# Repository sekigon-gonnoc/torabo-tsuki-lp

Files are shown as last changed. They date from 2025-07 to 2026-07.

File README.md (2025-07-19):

# torabo-tsuki LP

torabo-tsuki LP（トラボ付きLP）はトラックボール付きの無線分割キーボードキットです。

トラックボール(25 or 19mm)の高さを低く抑えることで、キーを打つときや持ち運びの邪魔になりにくくなっています。
無線接続に適したハードウェア・ソフトウェア構成により低消費電力を実現しており、連続して数か月間使用可能です。バッテリーは乾電池なので、残量や安全性を気にしながら定期的に充電する必要がありません。

[BOOTH](https://nogikes.booth.pm/items/7200248)にて販売中です。

**MX版の情報は[こちら](https://github.com/sekigon-gonnoc/torabo-tsuki)**

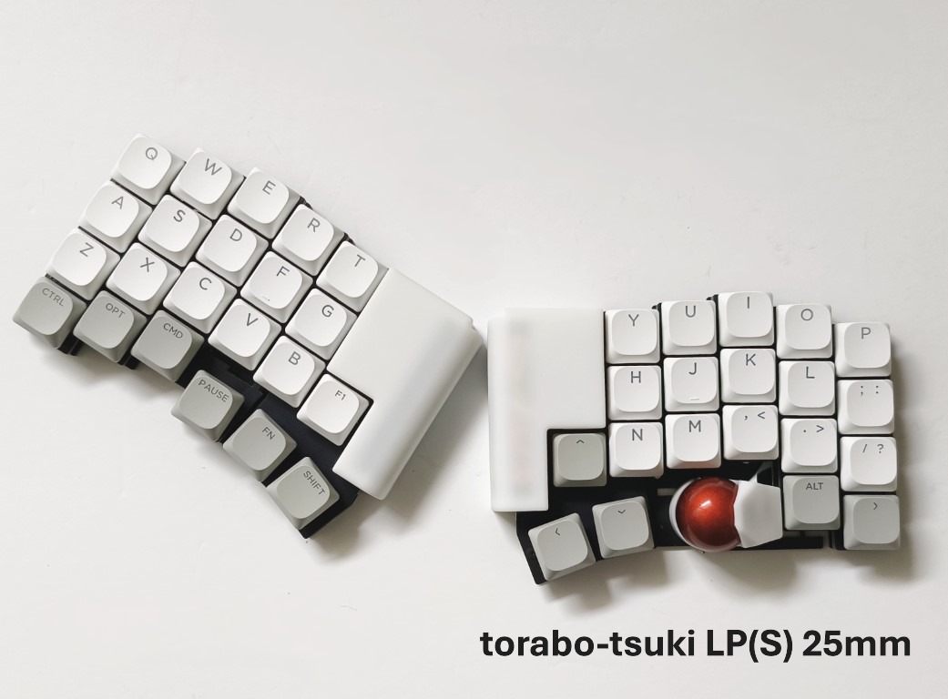
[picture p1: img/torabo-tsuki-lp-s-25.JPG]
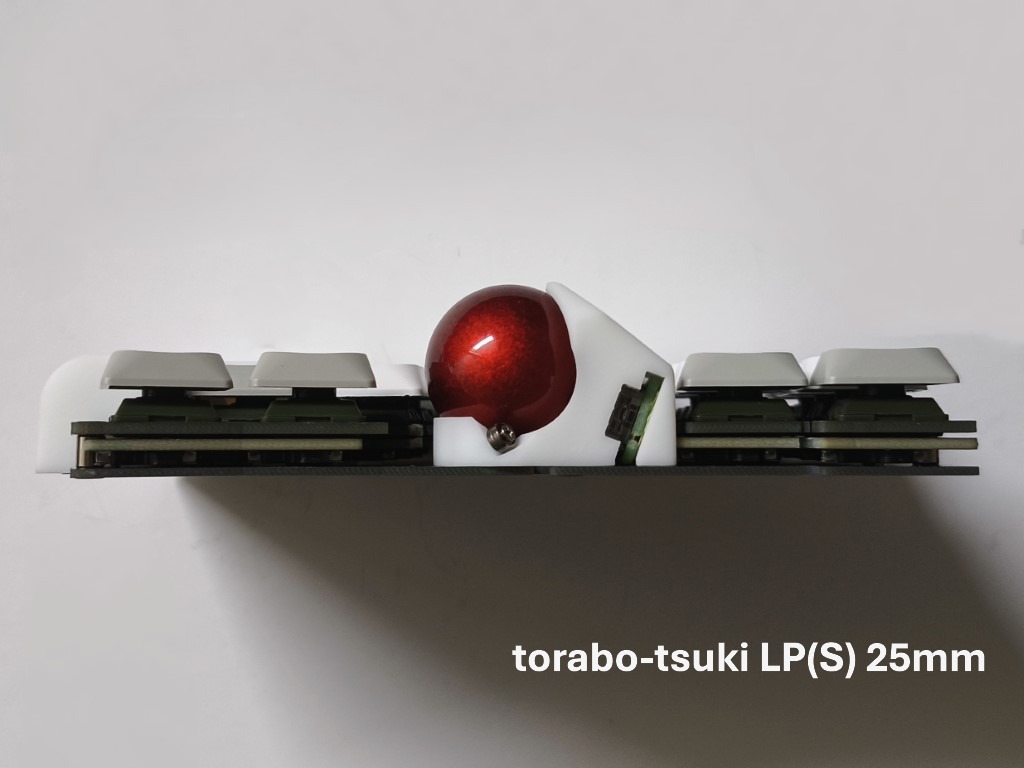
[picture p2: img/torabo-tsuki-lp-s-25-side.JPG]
|||
|-|-|
|Sサイズ, 右25mmボール|Sサイズ, 右25mmボール|
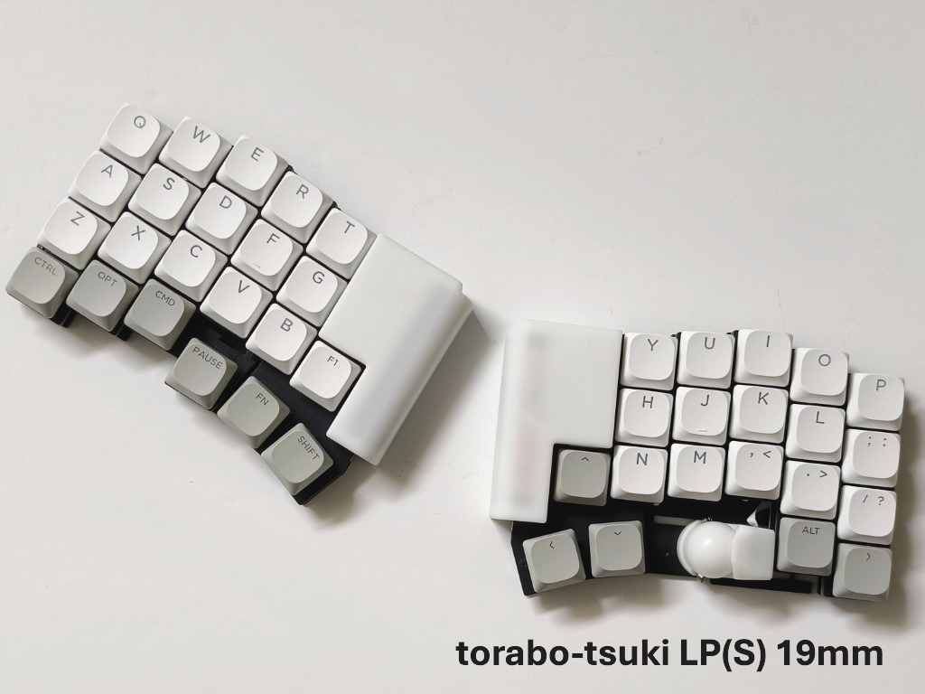
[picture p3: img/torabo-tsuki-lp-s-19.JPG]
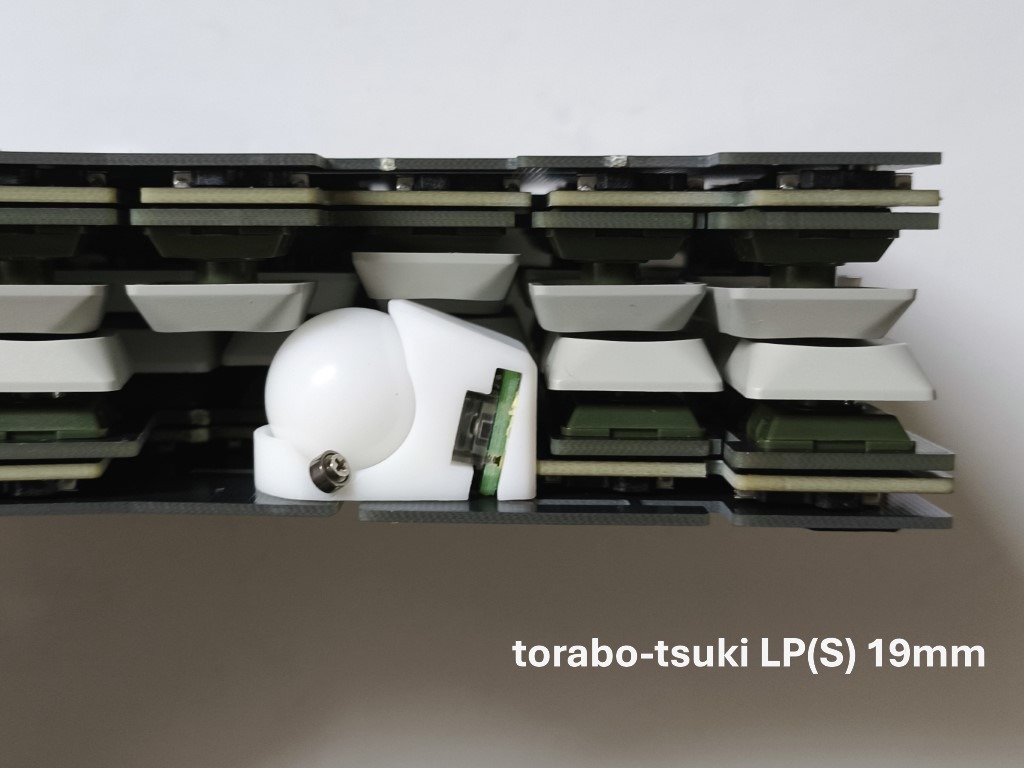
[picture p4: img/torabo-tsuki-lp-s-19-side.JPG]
|||
|Sサイズ, 右19mmボール|Sサイズ, 右19mmボール|

## [ビルドガイド](build-guide.md)

## 特徴

* 主要部品実装済み
  * ソケットやダイオードなどの部品は実装済みです。半田付けが必要な部品は電池ボックスだけです。
* 乾電池各1本で長期間動作
  * Ni-MH電池またはアルカリ電池で動作します。
  * 無線での使用にあわせて調整されたハードウェア・ソフトウェア構成により、乾電池でも数か月間利用できます。
* トラックボールの設置位置が調整可能
  * トラックボールを取り付ける位置を調整して、自分にとって一番操作しやすい位置に設置できます。ボールの高さを抑えたことでキーを打つときの邪魔になりにくなっています。
  * 左トラックボール、デュアルトラックボールにすることもできます。
  * トラックボールのサイズは25mmまたは19mmから選択できます。
* ZMK対応
  * keymap-editorやZMK Studioを使用して簡単にキーマップが変更できます。

## 使用上の注意

* 異臭や煙が出たときは、ただちに使用を中止して電源を切り電池を抜いてください。
* 電池から漏れた液が目に入った場合は、失明する恐れがあるのですぐにきれいな水でよく洗い、医師の診断を受けてください。
* 電池の+-を正しくセットしてください。
* 使い切った電池は速やかに取り出してください。
* 長期間使用しない場合は電池を取り出してください。

## 設計データについて

本リポジトリで基板・トラックボールケース・電池カバーの設計データを公開しています。

ライセンスにしたがって自由に利用していただいて構いませんが、問い合わせには対応しません。

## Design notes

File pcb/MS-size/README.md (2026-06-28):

\# torabo-tsuki LP(MS)

Mサイズの17mmピッチ版です。

動作未確認

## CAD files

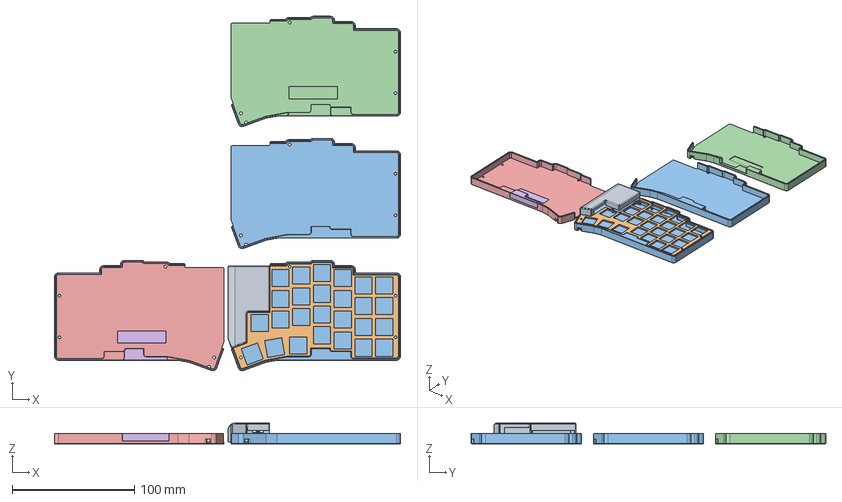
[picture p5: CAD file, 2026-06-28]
3d-models/FreeCAD/option/torabo-tsuki-lp-ms-simple-case.FCStd
283.4 x 290.4 x 17.2 mm
torabo-tsuki-lp-MS-top-key_PCB
case-key x 2
case-trackball
case-trackball001 (Mirror #2)
case-key001 (Mirror #3)

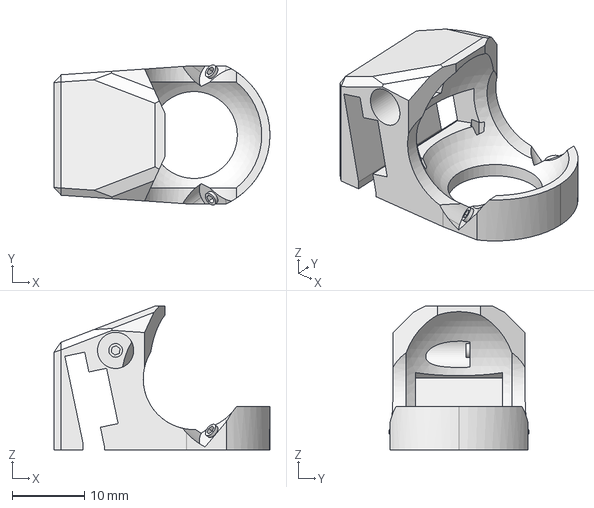
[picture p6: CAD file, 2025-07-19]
3d-models/FreeCAD/trackball-case-19mm.FCStd
29.8 x 19.4 x 19.8 mm

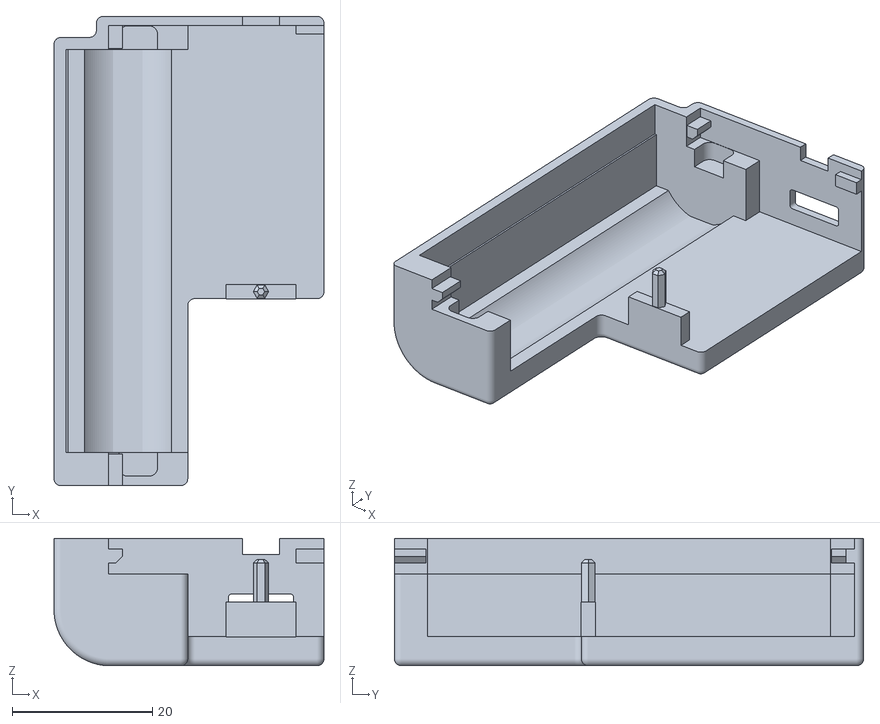
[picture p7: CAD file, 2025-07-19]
3d-models/STL/controller-cover-aa-Body-mirror.stl
38.5 x 67.0 x 18.2

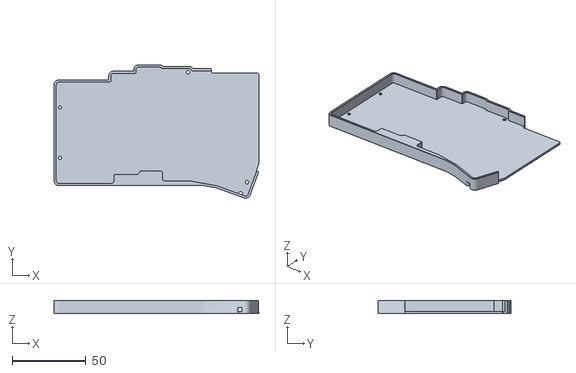
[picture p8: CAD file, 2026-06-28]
3d-models/STL/option/MS-size/torabo-tsuki-lp-MS-simple-case-left-key.stl
138.8 x 90.4 x 8.80

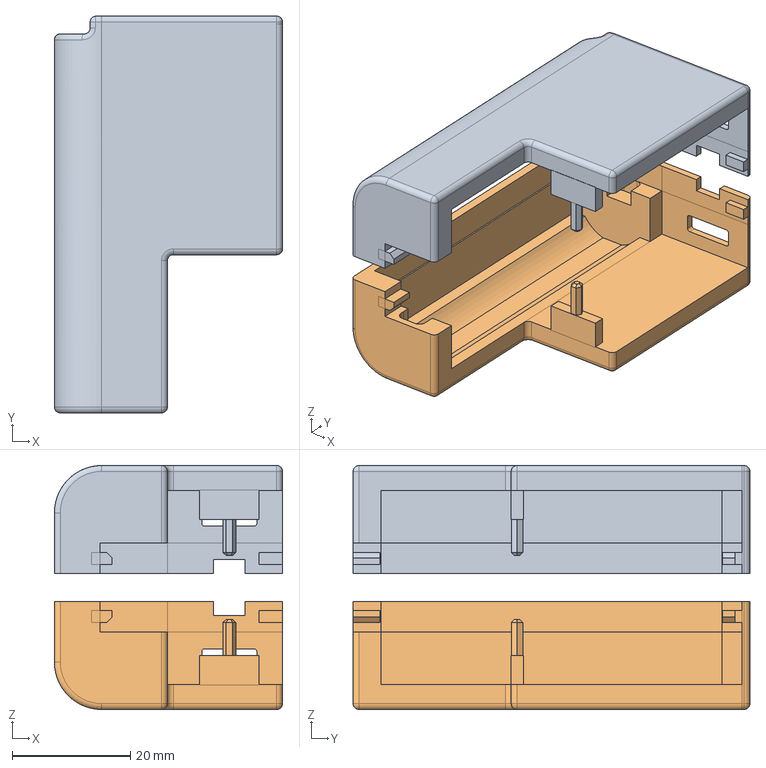
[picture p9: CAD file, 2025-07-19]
3d-models/FreeCAD/controller-cover-aa.FCStd
38.5 x 67.0 x 41.2 mm
Body (Mirror #1)

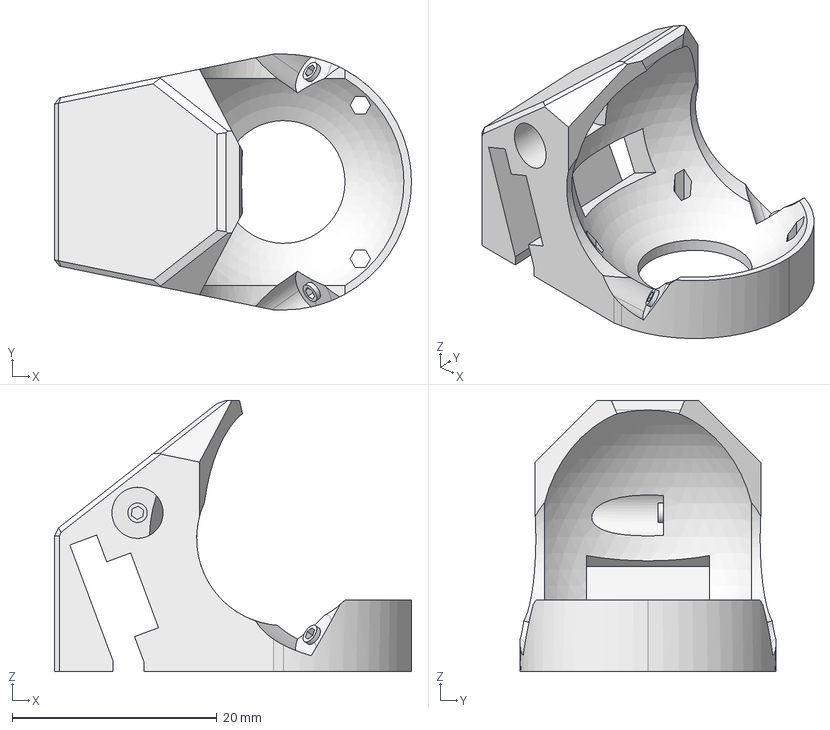
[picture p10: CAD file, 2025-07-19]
3d-models/FreeCAD/trackball-case-25mm.FCStd
34.9 x 25.0 x 26.5 mm

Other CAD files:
3d-models/STL/option/MS-size/torabo-tsuki-lp-MS-simple-case-right-key.stl
3d-models/STL/trackball-case-19mm-Body.stl
3d-models/STL/controller-cover-aa-Body.stl
3d-models/STL/option/MS-size/torabo-tsuki-lp-MS-simple-case-left-tb.stl
3d-models/STL/option/MS-size/torabo-tsuki-lp-MS-simple-case-right-tb.stl
3d-models/STL/trackball-case-25mm-Body.stl

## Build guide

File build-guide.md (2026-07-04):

# ビルドガイド

torabo-tsuki LPシリーズのビルドガイドです。V1とV2では電池ボックスの取り付け周りの手順が異なります。
自分が組み立てるのはどちらかを確認してから手順を進めてください。

## 同梱品

| 名称 | 数  |
| --- | --- |
| メイン基板 | 1 |
| トッププレート | 2 |
| ボトムプレート | 2 |
| 電池ボックス(単三 or 単四) | 2 |
| スペーサー(4.5mm) | 8 |
| ねじ(M2x3.5) | 18  |
| **トラックボール部品** | |
| トラックボールセンサー(14mmマウスセンサーモジュール) | 1 |
| フレキシブルケーブル(0.5mmピッチ、6P、100mm、電極同一面) | 1 |
| ベアリング(4x1.5x2 mm) | 3 |
| ねじ(M1.4) | 3 |
| **BMP Boost同梱の場合** | |
| BMP Boost | 2 |

## 別途必要な部品

| 名称 | 数 | 補足 |
| --- | ----- | --- |
| キースイッチ(Choc V2) | 42(S, XS), 50(M), 64(L) | |
| キーキャップ | 適量  | |
| 25mmトラックボール交換球  or 19.05mm POMボール | 1 | |
| コンスルー | 4 | 13ピン（高さ2.5mm）を使用してください。欠品している場合は12ピンを5個買って、1個を切り離して使ってください |
| 電池カバー、トラックボールケース(25mm or 19mm) | 1式 | 3Dプリントサービスや自前で出力してください。JLC3DPだと送料込みで$5くらいで製造できます（詳細は後述） |
| ゴム足 | 8 | GRIPLUSなど薄型の物がおすすめです |
| 乾電池 | 2 | S,M,Lは単三、XSは単四、Ni-MH可。USBで充電できるリチウム電池内蔵のものを使う場合、必ずキーボードから取り外してから充電してください |
| **オプション** |||
|ケース| 1式 | [シンプルケース](3d-models/STL/option)や有志が公開・販売しているデータを装着できます |
| **BMP Boost別売りの場合** | | |
| BMP Boost | 2 | BLE Micro Pro (無印)は使用できません。入手先:[BOOTH](https://booth.pm/ja/items/1177319), [遊舎工房](https://shop.yushakobo.jp/products/10737) |

## 必要な工具
- はんだごて、はんだ
- ニッパー
- ペンチ
- ドライバー
- （やすり）
- PC
- USBケーブル

## 3Dプリント部品の製造(JLC3DP利用)

[JLC3DP](https://jlc3dp.com/jp/3d-printing-quote)にアクセスします。

[3d-models/STL](3d-models/STL/)フォルダのSTLファイルの中身をJLC3DPにアップロードします。トラックボールケースはサイズが2種類あります。製造時に片方に決めてもいいですし、両方頼んで届いてから考えてもいいです。

電池カバーは、S,M,Lの場合はaaを、XSの場合はaaaを使用してください。V2ではV1から形状が若干変わっています。過去にV1を組み立て済みで、今回V2を組み立てる方は、改めてデータをダウンロードしてください。

また、[シンプルケース](3d-models/STL/option)、[テンティングケース](https://github.com/sekigon-gonnoc/torabo-tsuki-lp-tenting-case)や、有志が公開・販売しているデータを一緒に製造することもできます。ご自分でデザインしたい場合は[シンプルケースのCADデータ](3d-models/FreeCAD/option/torabo-tsuki-lp-simple-case.FCStd)をご活用ください。

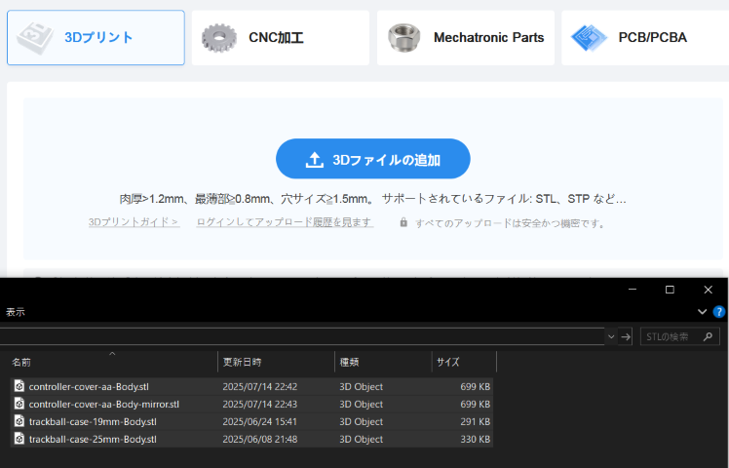
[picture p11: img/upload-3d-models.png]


電池カバー、トラックボールケースについての商品概要は`Enclosure..`から`Plastic Enclosure`を選択します。
ケースについては`Office Appliance...`から`Plastic Keyboard Enclosure`を選択してください。

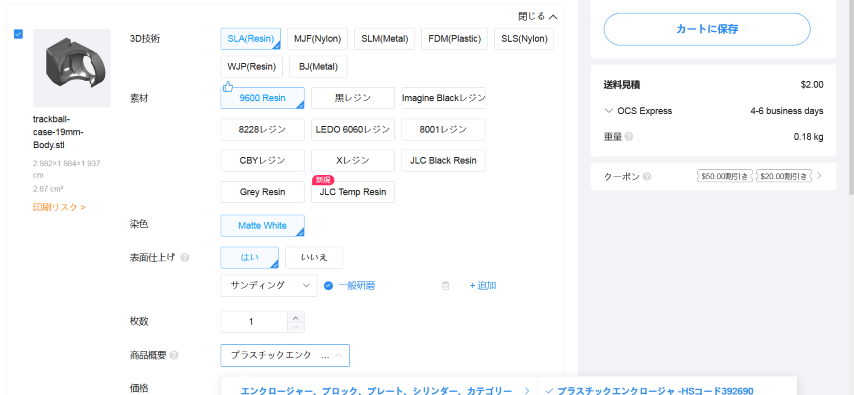
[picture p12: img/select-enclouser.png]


モデルのサムネイルの下に`印刷リスク`の表示がある場合は`はい`をチェックしてください。

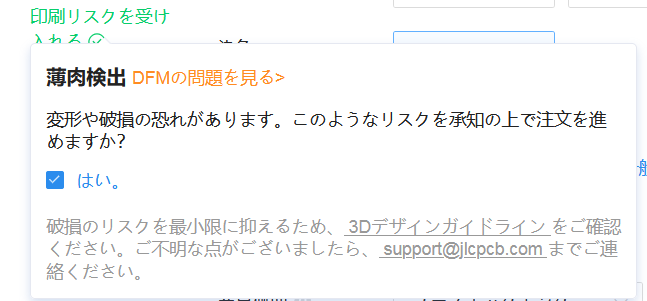
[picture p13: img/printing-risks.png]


カートに保存し、注文手続きを進めます。配送方法はOCSを選択すると2ドルで配送してもらえます（2025年7月時点、月3回まで）。

発注履歴が表示されるようになった状態で数分経ってからタブをリロードすると、ファイル名の横に!マークが表示されることがあります。

その場合は!マークをクリックし、`はい`を選択してください。

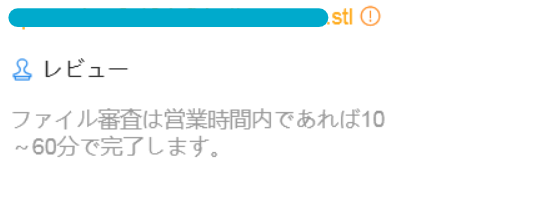
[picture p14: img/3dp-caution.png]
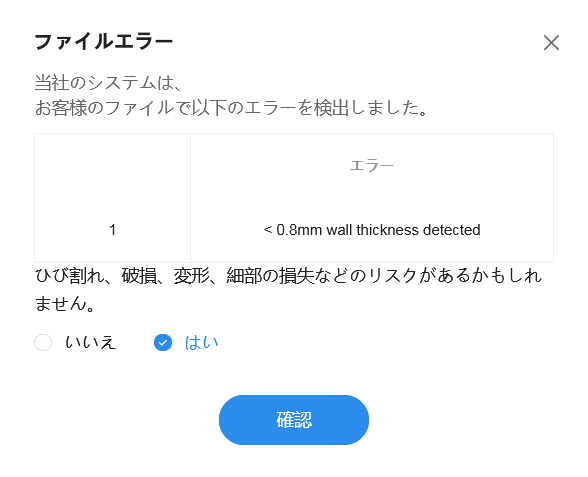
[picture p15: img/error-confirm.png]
|  |  |
| --- | --- |

JLC3DPによるレビュー中にメールで問い合わせが来る場合がありますが、そのまま製造するように依頼してください。
気になる人は自分でCADデータを修正してください。

## 組立手順

### メイン基板のレール部分を折って切り離す

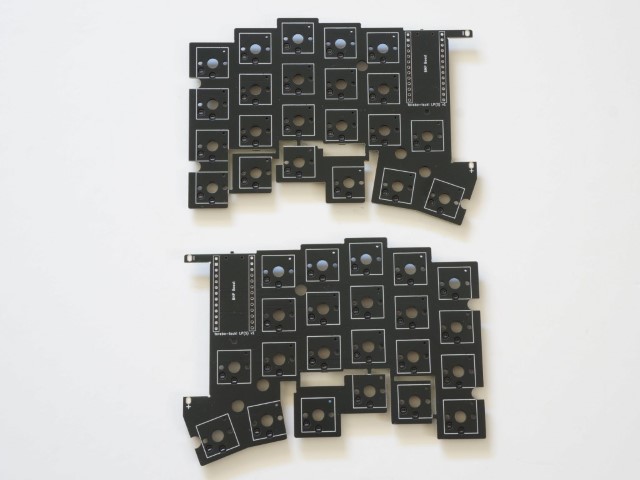
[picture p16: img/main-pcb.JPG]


### メイン基板・トッププレートのトラックボール搭載部分と、トラックボールを搭載しないほうのボトム基板の余剰部分を切り離す

シンプルケースを装着する場合は、ボトムプレートは両側とも余剰部分を切り離します。

ニッパーでそのまま切り離せない場合は、表裏に切れ目を入れてから折り取ることもできますが、ほかの配線を傷つけないように注意してください。

> [!caution]
> 向きを間違えないように注意してください。下記画像は右側にトラックボールを搭載する例です。

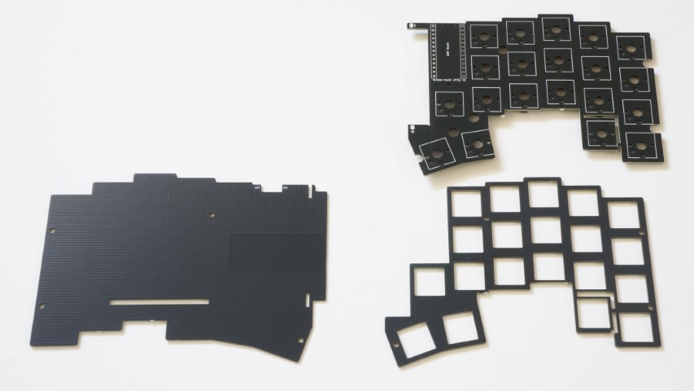
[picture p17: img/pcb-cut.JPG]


### (V1の場合)電池ボックスをはんだ付けする

* 電池ボックスの足を折り曲げます。
  * XSに単四電池ケースを取り付ける場合は基板上のマークよりすこし上に寄せてください。基板の穴はBMP Boost側を使います。マイナス極が上側です。
* ボトムプレートに電池ボックスを載せ、その上からメイン基板を載せます。向きに注意してください。
* 余った足を短く切ってからはんだ付けします。メイン基板とボトム基板がぴったりくっついた状態ではんだ付けするようにしてください。

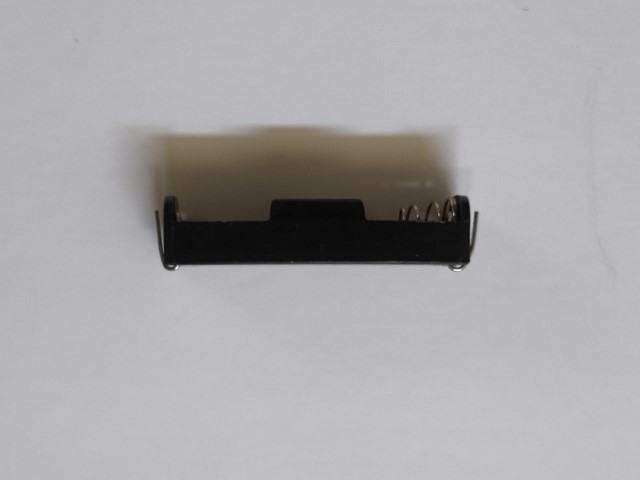
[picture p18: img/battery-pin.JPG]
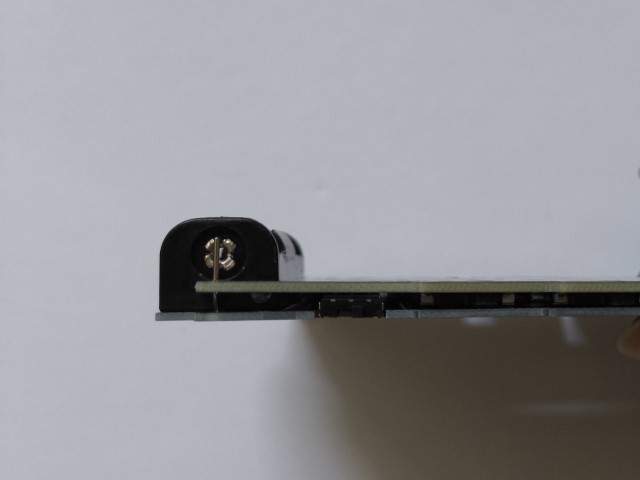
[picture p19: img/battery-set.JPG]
|||
|-|-|
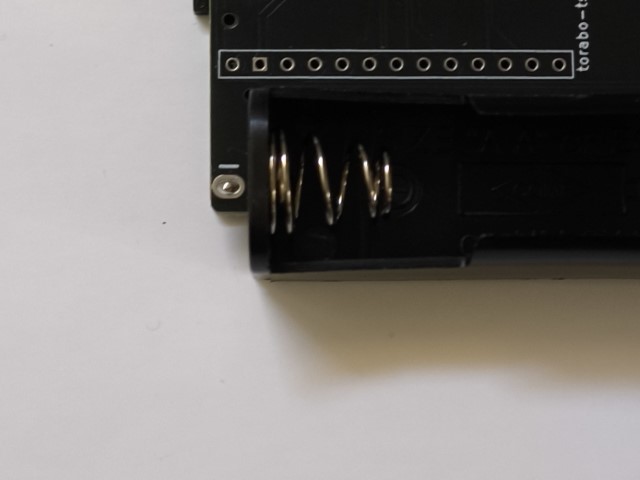
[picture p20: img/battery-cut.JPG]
|||

||
|-|
|単四電池ケースの取り付け位置|

### (V2の場合)電池ボックスを基板に差し込む

torabo-tsuki LP V2では電池ボックスもソケットに差し込むだけで取り付けられます。
ソケットの位置に合わせて電池ボックスの足を折り曲げてから差し込みます。
S,M,Lではパーツ配置の都合で斜め方向に足を曲げ、XSでは真上に曲げてください。

|||
|-|-|
|S,M,L|XS|

* 電池ボックスのピンを折り曲げます。横から見たときピンが真上に向くように折り曲げていきます。手で90度まで曲げても手を離すと手前まで戻ってしまうので、以下のような手順で進めてください。
* 一度曲げた部分を元に戻そうとすると金属疲労で折れてしまうのでご注意ください。
  
  1. 電池ボックスのピン先端をつかみ、真横を向くように曲げます。手を離すと下に少し戻るので、様子を見ながら少しずつ曲げ量を増やします。S,M,Lではパーツの配置の都合上、下から見たとき少し斜めになるようにしてください。XSは真っすぐで大丈夫です。

      ||
      |-|
      |横から見たとき|
      ||
      |S,M,L|
      ||
      |XS|

  2. ボトムプレートを間に挟みながらもう90度曲げます。手を離すと90度より手前に戻りますが、そのまま次に進みます。

      |||
      |-|-|

  3. 電池ボックスのピン先端をつかんでさらに曲げます。電池ボックスと干渉するので、このステップでも90度までは曲がりません。

      

  4. 電池ボックスの横に空いている穴の上端のところで、電池ボックスのピンをニッパーでカットします。

      

  5. ピンの先端を電池ボックスの横の穴に押し込むように曲げます。手を離したときにピンが真上を向くところまで曲げてください。

      

* 電池ボックスをメイン基板に差し込む
  * 電池ボックスのピンが、基板の板バネでしっかり挟みこまれていることを確認してください

|||
|-|-|

### トッププレート・メイン基板にスイッチを差し込む

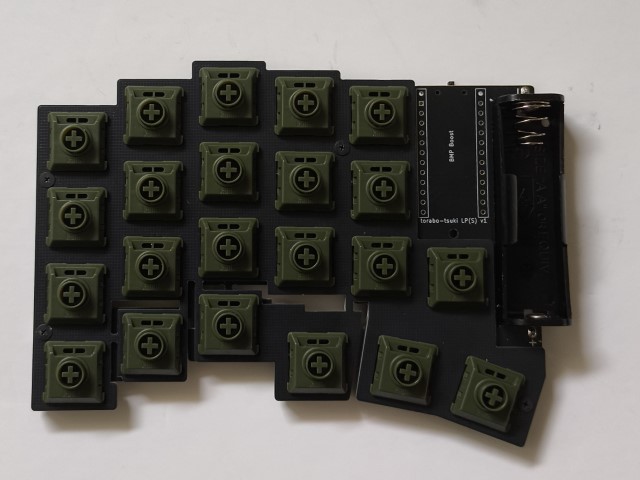
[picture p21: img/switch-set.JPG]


### メイン基板にBMP Boostをコンスルーで取り付ける

* はんだ付けは不要です。
* コンスルーの向きは揃えてください。

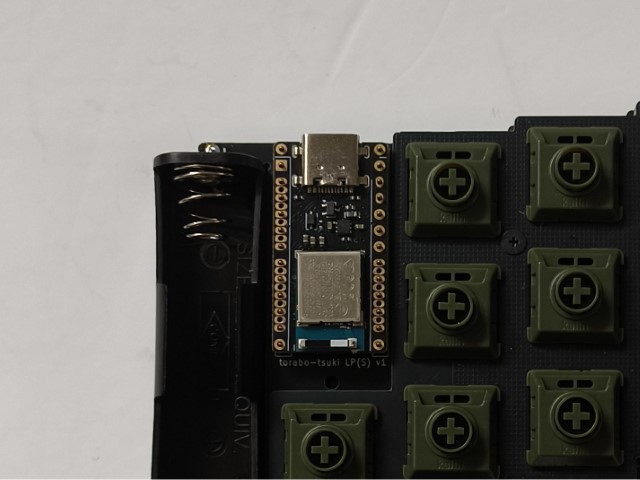
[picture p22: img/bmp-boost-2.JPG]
|||
|-|-|

### ファームウェアを書きこむ

* スイッチをOFFにした状態で、BMPをPCにUSBケーブルで接続します。
* BLEMICROPROという名前のストレージがマウントされたら、中身にINFO_UF2.TXTがあることを確認してください。
* [Releases](https://github.com/sekigon-gonnoc/zmk-keyboard-torabo-tsuki-lp/releases)からファームウェアのuf2ファイルをダウンロードします。
* uf2ファイルを1つ選んでストレージにコピーしてください。トラックボールがあるほうがCentral、ないほうがPeripheralです。
  * たとえば右側トラックボールで組み立てた場合、右手に`torabo_tsuki_lp_right_central`、左手に`torabo_tsuki_lp_left_peripheral`を書き込んでください。
* 書き込みが完了したら一度USBケーブルを抜き、スイッチをONにした状態でUSBケーブルを差し直すとキーボードとして動作します。

### トッププレートにスペーサーをねじ止めする

* スペーサーをトッププレートにねじ止めします。

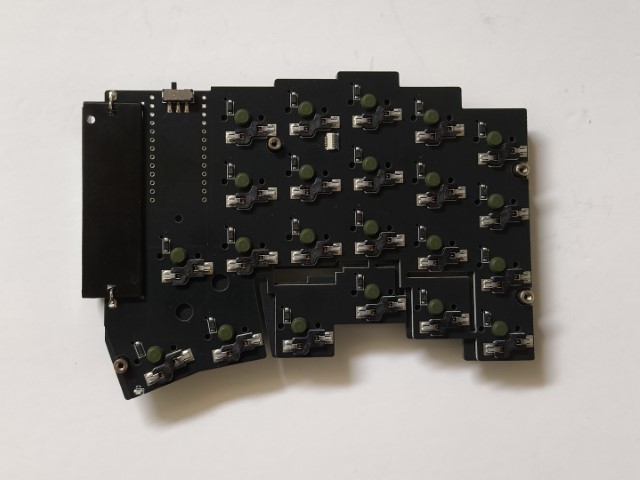
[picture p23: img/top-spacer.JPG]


### トラックボールケースにベアリングをネジで固定する

* ケースに空いている穴にねじを押し込みながら回すようにしてベアリングを固定します。
* ベアリングは多少ガタつきますが問題ありません。

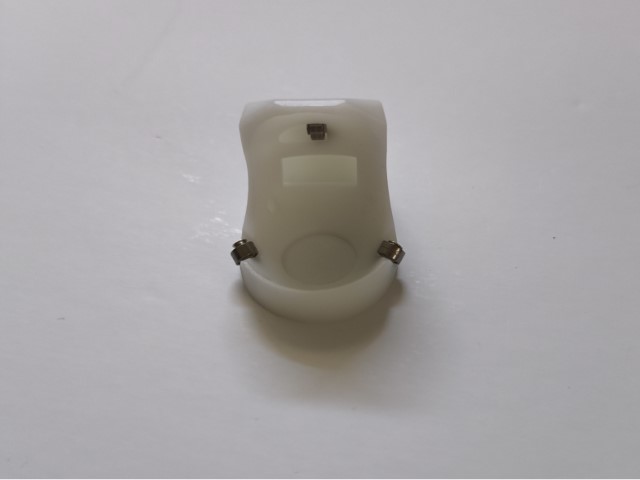
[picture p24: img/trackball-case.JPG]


### トラックボールセンサーにケーブルを差し込む

* コネクタのフラップ（黒い部分）を上に持ち上げ、トラックボールのケーブルをしっかり奥まで差し込み、フラップを下げます。
  * 無理な力をかけると破損します。[コネクタの操作方法と注意点をよく確認してください](https://www.hirose.com/ja/product/document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)

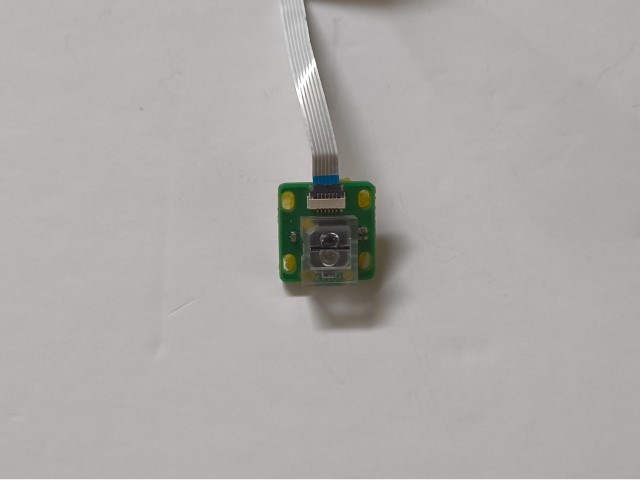
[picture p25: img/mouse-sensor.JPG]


### トラックボールのケーブルをメイン基板のコネクタに差し込む

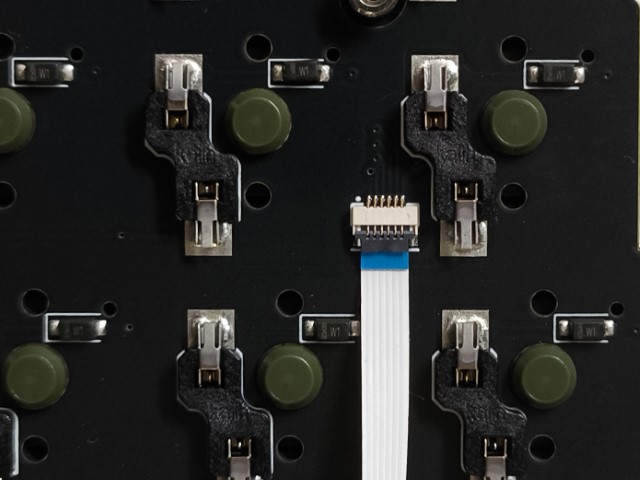
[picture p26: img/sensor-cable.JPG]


### センサーの動作確認をする

* USBケーブルでPCとBMP Boostを接続します。
* センサーのレンズ側を机から2mmくらい浮かせてセンサー基板を動かしたり、レンズの上空を指で動かしたりしてマウスカーソルが動くならば、センサーは正常に動作しています。 
* センサーの動作確認ができたらUSBケーブルは取り外してください。

### トラックボールセンサーをケースに取り付ける

* ケースの中央あたりまで差し込みます。
* 緩すぎてすぐ抜けてしまう場合は紙などを挟んで調節してください。
* きつすぎる場合は背面の突起を削ってください。
* トラックボールの反応が悪い場合には取り付け位置を調整してください。

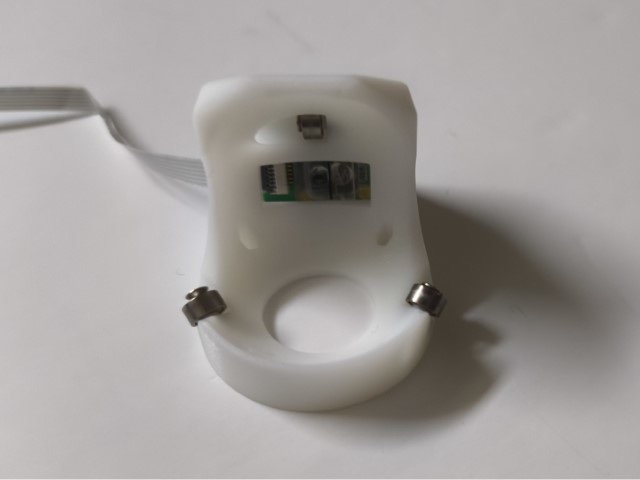
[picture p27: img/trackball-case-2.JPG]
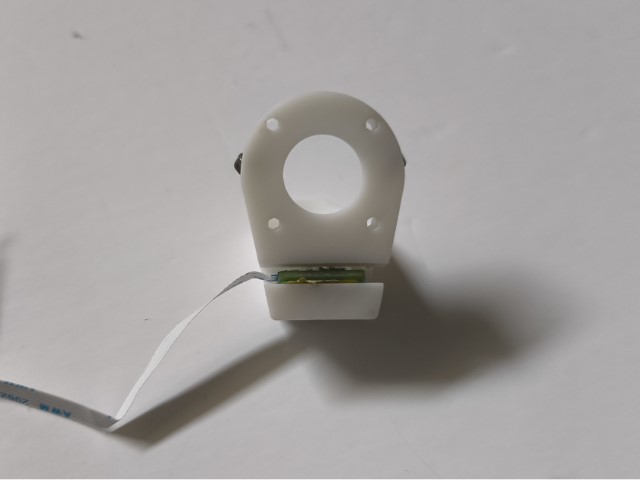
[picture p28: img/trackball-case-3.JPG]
|||
|-|-|

### ボトムプレートを取り付け、ボトムプレートにトラックボールケースを取り付ける

* シンプルケースを装着する場合はケースも一緒にねじ止めしてください。

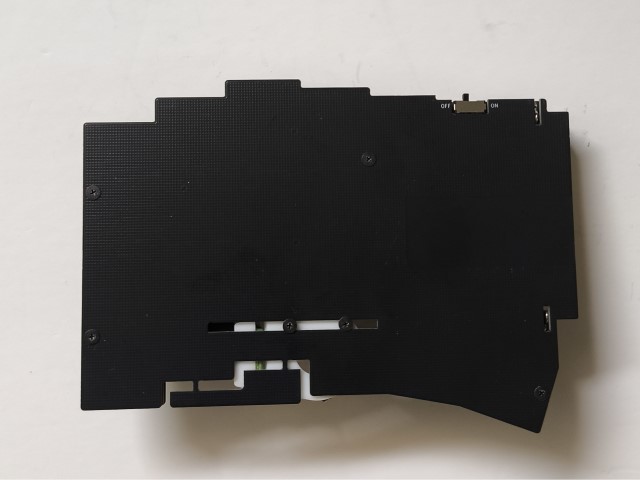
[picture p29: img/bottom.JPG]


### (V2の場合)電池ボックスの余った足をカットする

* 電池ボックスをボトムプレートに接地するように下側に寄せて、余った足をニッパーでカットしてください。
  * 電池ボックスがボトムプレートから浮いた状態でカットしてしまうと、使用中に電池ボックスが下側に抜けてしまう可能性があるので、注意してください。

|||
|-|-|

### トラックボールケースにボールを入れる

* ボールをケースに押し込んで入れます。

### 電池を入れる

* 電池をケースに入れます。向きに注意してください。

### 電池カバーを付ける

* 外側の爪2箇所(XSは1箇所)をメイン基板にひっかけます。
* 内側の爪（USBコネクタ横の爪）を引っ張りながらメイン基板にひっかけます。

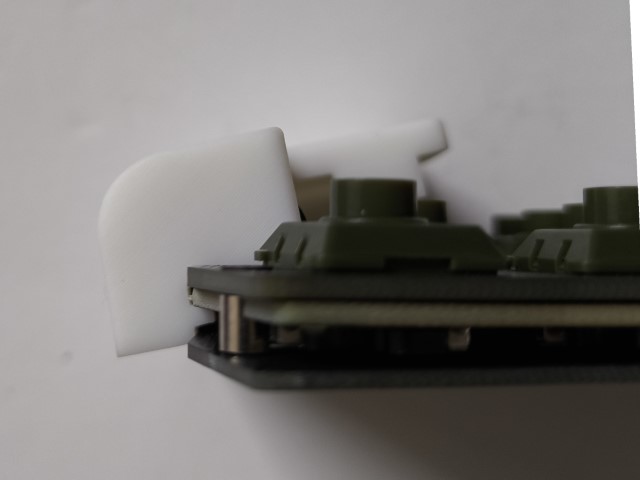
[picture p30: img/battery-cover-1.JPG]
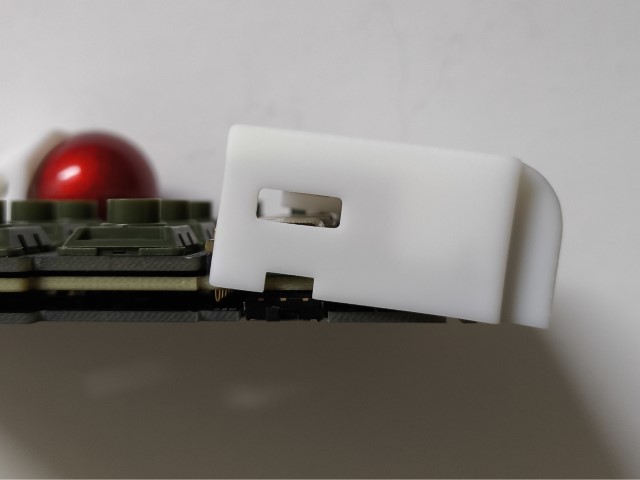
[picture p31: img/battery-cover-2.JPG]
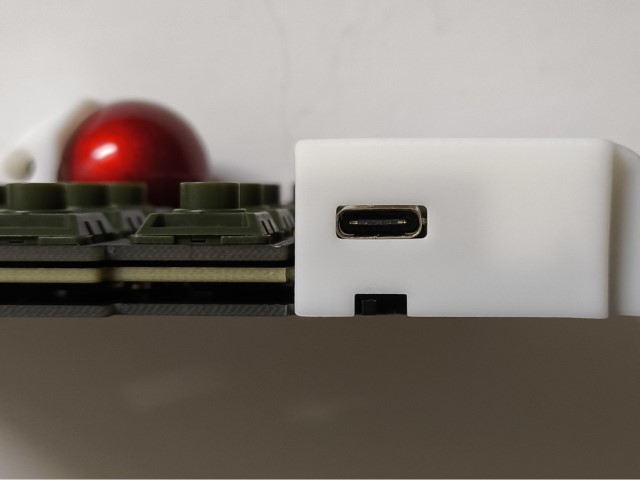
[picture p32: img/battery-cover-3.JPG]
||||
|-|-|-|

> [!caution]
> V2基板に対してV1用のカバーを無理やり取り付けようとした場合、電池ボックス用のソケットが破損します。
> V2用カバーを取り付ける場合も基板側面にカバーを確実に押し当てなが内側の爪をひっかけるようにしてください。
>
> 

* ボトムプレートを外した場合、下の図で赤く示した4箇所で固定されています

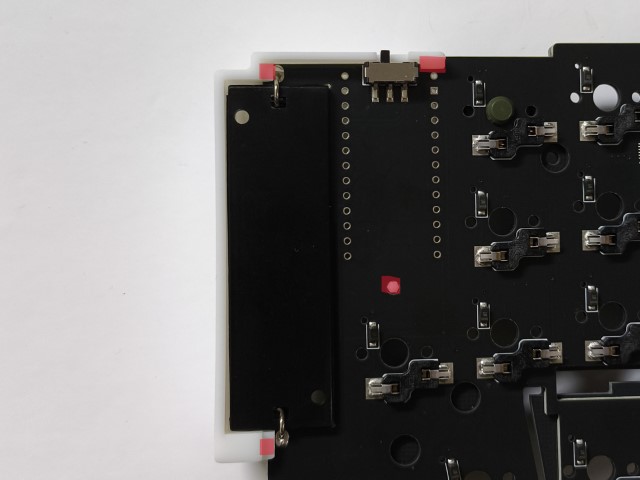
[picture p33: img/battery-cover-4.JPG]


### ゴム足を付ける

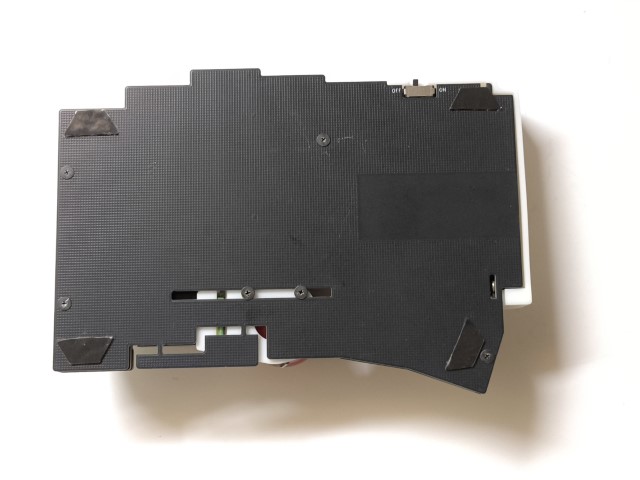
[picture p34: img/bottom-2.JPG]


### キーキャップを取り付ける

**以上で組立は完了です、お疲れさまでした。**

## 使い方

### 電源の説明

* スライドスイッチをON側に切り替えると電源が入ります。電源がONするとLEDが点滅します。
* 有線接続する場合でもスライドスイッチはON側にしてからケーブルを接続してください。OFFの状態で接続した場合はブートローダが起動します。

### LEDの説明

親指のところに赤色LEDがついています。

* 起動時：点滅回数(1~3)でバッテリー残量を示しています
* ペアリング中：ペアリング先を探している間、数秒に1回点灯します。ペアリングが完了すると1回点灯します。



### 無線接続

* 両手のスライドスイッチをONして、接続先のデバイスでペアリングします。

### キーマップを変更する

* [ZMK Studio](https://zmk.studio/)または[Keymap-Editor](https://nickcoutsos.github.io/keymap-editor/)でキーマップが変更できます。
* Keymap-Editorを使用する場合は[zmk-keyboard-torabo-tsuki-lp](https://github.com/sekigon-gonnoc/zmk-keyboard-torabo-tsuki-lp)をクローンして編集してください。
  * Keymap-Editorの仕様によりconfig/info.jsonはLサイズ用になっているため、S,Mサイズには存在しないキーも表示されます。
  * [ファームウェアの書き込み方](#ファームウェアを書きこむ)を参考にして、新しく作ったuf2ファイルを書き込んでください。

## トラブルと対策

* 初期不良による部品交換が必要な場合や、組立ミスのため一部部品だけ購入したい場合はBOOTHからメッセージをお送りください。
* 組立にあたってのトラブルで相談がある場合は本リポジトリのissueに投稿してください。
  * **投稿の前に既存のissueを検索してください**

## FAQ

まずはZMKのドキュメントを確認してください。

### ペリフェラル側をUSB接続してもキー入力できない

* ZMKの仕様です
* セントラルとペアリングしたうえでセントラル側を有線または無線接続してください

### 無線接続に問題がある

* 電源が入っているか確認してください。
* ZMKのドキュメントを確認してください。
* settings_resetのファームウェアを書き込む場合、uf2を書き込むだけでなく、一度再起動が必要です
  * スイッチOFF→USB接続→書き込み→USB外す→スイッチON→USB再接続でsettings_resetのファームウェアが動作して、設定が初期化されます

### トラックボールの動きだしが遅い

* 一定時間ボールを動かさなかった場合にセンサーがスリープ状態になります。スリープ状態の解除に少し時間がかかるため動き出しが遅くなる場合があります。

### トラックボールの動きがおかしい/動かない

* [センサーの位置調整](#トラックボールセンサーをケースに取り付ける)をご確認ください。
* トラックボールのケーブルがコネクタにしっかりささっているか確認してください。
* センサーの仕様として、最大速度24inch/s、最大加速度10Gという制約があります。25mmボールの回転速度に換算すると9回転/sが最大速度で、これを超える速度で回転させた場合にはカーソルが逆方向に動くことがあります。

### 一部のキーが入力できない

* スイッチの足が折れ曲がっていないか、BMP Boostが浮いていないか確認してください。

### トラックボールの移動速度を変えたい/オートマウスレイヤー/スクロールレイヤーを使用したい

* ZMKのinput processorを使用してください。

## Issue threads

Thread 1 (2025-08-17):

[トラブルシューティング]: トラックボールセンサーが全く反応しない

Cuvelia, 2025-08-17:
## torabo-tsukiのトラブルシューティング

このテンプレートを使用して、キーボードの問題に関する情報を提供してください。

組み立て関連の問題をチェックしたら、対応するトラブルシュートの項目をすべてチェックしてください。
  例：ファーム書き込みの問題のいずれかにチェックを入れた -> ファームウェア書き込みのトラブルシュートの項目をすべてチェックしてください

問題の詳細やチェックした結果を、詳細説明の項目で詳しく説明してください。

フォーマットにのっとっていない場合は自動的にIssueがクローズされます。修正してReopenしてください。

最後に、BOOTHのメッセージからIssueのURLを送信してください。購入者以外のサポートはしません。

- [x] ビルドガイドの'トラブルと対策'の項目を熟読した

### 問題の分類

- キット内容の問題
  - [ ] 部品が不足している
  - [ ] 部品が破損している
  - [ ] はんだ済みの部品に問題がある
  - [ ] 組み立てに失敗したため、部品を追加購入したい
  - [ ] その他のキット内容の問題
- ファームウェア書き込みの問題
  - [ ] ファームウェアが書き込めない
  - [ ] その他のファームウェア書き込みの問題
- キーボードの電源の問題
  - [ ] LEDが点灯しない
  - [ ] LEDは点灯するがペアリングしない
  - [ ] その他の電源の問題
- キー入力の問題
  - [ ] 特定のキーが反応しない
  - [ ] キーの反応が遅い
  - [ ] その他のキー入力の問題
- トラックボールの問題
  - [x] トラックボールがまったく反応しない
  - [ ] トラックボールの動きがスムーズでない
  - [ ] カーソルの動きが不規則
  - [ ] その他のトラックボールの問題
- ペアリングの問題
  - [ ] 両手とも無線で入力できない
  - [ ] 片手（peripheral側が無線で入力できない）
  - [ ] その他のペアリングの問題
- 無線接続中の入力の問題
  - [ ] ペアリングができない
  - [ ] 接続が頻繁に切れる、接続の遅延が大きい
  - [ ] その他の無線接続中の入力の問題
- その他
  - [ ] その他

### トラブルシュート

- キット内容のトラブルシュート
  - [ ] BOOTHで連絡した <!-- ここをチェックする場合、issueは立てないでください -->
- ファームウェア書き込みのトラブルシュート
  - [ ] ZMKのドキュメント、FAQを確認した
  - [ ] BMPのブートローダーが起動しているかどうか、ストレージのなかのINFO_UF2.TXTを確認してからファームウェアを書き込んだ
- キーボードの電源のトラブルシュート
  - [ ] 電源ONの状態で、電池ボックスの-側とBMPの0番ピン(ランドが四角いピンの1個上)の電圧が1V以上になっている
  - [ ] 電池ボックスとスイッチのはんだ付けを再確認した <!-- 画像を添付してください -->
- キー入力のトラブルシュート
  - [ ] ZMKのドキュメント、FAQを確認した
  - [ ] central側にキーマップが設定されていることをzmk-studioで確認した
  - [ ] キースイッチの足が折れ曲がっていないか確認した
  - [ ] コンスルーの足が折れ曲がっていないか確認した
  - [ ] BMPを取り付け直した
  - [ ] BMPを左右で入れ替えて、メインの基板とBMPのどちらに問題があるか絞りこんだ
- トラックボールのトラブルシュート
  - [x] ケーブルの接続を再確認した
  - [x] センサーの取付位置を調整してみた
  - [x] 組立中、ケースに取り付ける前にセンサーの動作確認を実施した
  - [ ] トラックボールモジュールの仕様(最大速度24inch/s、最大加速度10G)について理解した
- ペアリングのトラブルシュート
  - [ ] ZMKのFAQを確認し、関連するトラブルシュートを実施した(実施した内容を詳細説明に記載してください)
- 無線接続中の入力のトラブルシュート
  - [ ] ZMKのFAQを確認し、関連するトラブルシュートを実施した(実施した内容を詳細説明に記載してください)
  - [ ] ほかのデバイスに接続して動作確認した

### 問題の詳細説明
キーボードの組み立ての過程で、ファームウェアの書き込みの作業まで問題なく出来ました(キースイッチを押して問題なく打てていることを確認)。その後の[センサーの動作確認をする](https://github.com/sekigon-gonnoc/torabo-tsuki-lp/blob/master/build-guide.md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)の作業を行っているのですが、トラックボールのセンサーが全く反応しません。何度も書き込むべきファームウェアを確認の上、書き込み直してセンサーの反応を確認しているのですが、解決しませんでした。

### トラブルシュートの詳細説明
- ケーブルの接続確認ですが、ケーブルをそれぞれコネクタに奥まで差し込んでいます
- センサーの取り付け位置ですが、トラックボールの動作確認の際にセンサーをケースの中央まで差し込んでからボールを動かして確認しているのですが、全く反応しません

### 環境情報
- ファームウェアバージョン: [Releases](https://github.com/sekigon-gonnoc/zmk-keyboard-torabo-tsuki-lp/releases)のlatest
- 接続方法（USB/Bluetooth/その他）: USB
- 接続しているデバイス（PC/Mac/その他）: PC
- OSとバージョン: Windows 11 Pro 24H2

### 追加情報
#### トラックボールのケーブルの差し込み状態
以下のようにケーブルを差し込んでいます。
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

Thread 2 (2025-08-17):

[トラブルシューティング]: トラックボールセンサーが全く反応しない

Cuvelia, 2025-08-17:
## torabo-tsukiのトラブルシューティング

このテンプレートを使用して、キーボードの問題に関する情報を提供してください。

組み立て関連の問題をチェックしたら、対応するトラブルシュートの項目をすべてチェックしてください。
  例：ファーム書き込みの問題のいずれかにチェックを入れた -> ファームウェア書き込みのトラブルシュートの項目をすべてチェックしてください

問題の詳細やチェックした結果を、詳細説明の項目で詳しく説明してください。

フォーマットにのっとっていない場合は自動的にIssueがクローズされます。修正してReopenしてください。

最後に、BOOTHのメッセージからIssueのURLを送信してください。購入者以外のサポートはしません。

- [x] ビルドガイドの'トラブルと対策'の項目を熟読した

### 問題の分類

- キット内容の問題
  - [ ] 部品が不足している
  - [ ] 部品が破損している
  - [ ] はんだ済みの部品に問題がある
  - [ ] 組み立てに失敗したため、部品を追加購入したい
  - [ ] その他のキット内容の問題
- ファームウェア書き込みの問題
  - [ ] ファームウェアが書き込めない
  - [ ] その他のファームウェア書き込みの問題
- キーボードの電源の問題
  - [ ] LEDが点灯しない
  - [ ] LEDは点灯するがペアリングしない
  - [ ] その他の電源の問題
- キー入力の問題
  - [ ] 特定のキーが反応しない
  - [ ] キーの反応が遅い
  - [ ] その他のキー入力の問題
- トラックボールの問題
  - [x] トラックボールがまったく反応しない
  - [ ] トラックボールの動きがスムーズでない
  - [ ] カーソルの動きが不規則
  - [ ] その他のトラックボールの問題
- ペアリングの問題
  - [ ] 両手とも無線で入力できない
  - [ ] 片手（peripheral側が無線で入力できない）
  - [ ] その他のペアリングの問題
- 無線接続中の入力の問題
  - [ ] ペアリングができない
  - [ ] 接続が頻繁に切れる、接続の遅延が大きい
  - [ ] その他の無線接続中の入力の問題
- その他
  - [ ] その他

### トラブルシュート

- キット内容のトラブルシュート
  - [ ] BOOTHで連絡した <!-- ここをチェックする場合、issueは立てないでください -->
- ファームウェア書き込みのトラブルシュート
  - [ ] ZMKのドキュメント、FAQを確認した
  - [ ] BMPのブートローダーが起動しているかどうか、ストレージのなかのINFO_UF2.TXTを確認してからファームウェアを書き込んだ
- キーボードの電源のトラブルシュート
  - [ ] 電源ONの状態で、電池ボックスの-側とBMPの0番ピン(ランドが四角いピンの1個上)の電圧が1V以上になっている
  - [ ] 電池ボックスとスイッチのはんだ付けを再確認した <!-- 画像を添付してください -->
- キー入力のトラブルシュート
  - [ ] ZMKのドキュメント、FAQを確認した
  - [ ] central側にキーマップが設定されていることをzmk-studioで確認した
  - [ ] キースイッチの足が折れ曲がっていないか確認した
  - [ ] コンスルーの足が折れ曲がっていないか確認した
  - [ ] BMPを取り付け直した
  - [ ] BMPを左右で入れ替えて、メインの基板とBMPのどちらに問題があるか絞りこんだ
- トラックボールのトラブルシュート
  - [x] ケーブルの接続を再確認した
  - [x] センサーの取付位置を調整してみた
  - [x] 組立中、ケースに取り付ける前にセンサーの動作確認を実施した
  - [x] トラックボールモジュールの仕様(最大速度24inch/s、最大加速度10G)について理解した
- ペアリングのトラブルシュート
  - [ ] ZMKのFAQを確認し、関連するトラブルシュートを実施した(実施した内容を詳細説明に記載してください)
- 無線接続中の入力のトラブルシュート
  - [ ] ZMKのFAQを確認し、関連するトラブルシュートを実施した(実施した内容を詳細説明に記載してください)
  - [ ] ほかのデバイスに接続して動作確認した

### 問題の詳細説明
キーボードの組み立ての過程で、ファームウェアの書き込みの作業まで問題なく出来ました(キースイッチを押して問題なく打てていることを確認)。その後の[センサーの動作確認をする](https://github.com/sekigon-gonnoc/torabo-tsuki-lp/blob/master/build-guide.md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)の作業を行っているのですが、トラックボールのセンサーが全く反応しません。何度も書き込むべきファームウェアを確認の上、書き込み直してセンサーの反応を確認しているのですが、解決しませんでした。

### トラブルシュートの詳細説明
- ケーブルの接続確認ですが、ケーブルをそれぞれコネクタに奥まで差し込んでいます
- センサーの取り付け位置ですが、トラックボールの動作確認の際にセンサーをケースの中央まで差し込んでからボールを動かして確認しているのですが、全く反応しません

### 環境情報
- ファームウェアバージョン: [Releases](https://github.com/sekigon-gonnoc/zmk-keyboard-torabo-tsuki-lp/releases)のlatest
- 接続方法（USB/Bluetooth/その他）: USB
- 接続しているデバイス（PC/Mac/その他）: PC
- OSとバージョン: Windows 11 Pro 24H2

### 追加情報
以下のようにケーブルを差し込んでいます。
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

sekigon-gonnoc, 2025-08-17:
確認ありがとうございます。いろいろとお手数をおかけして申し訳ありませんでした

Closed 2025-08-17.

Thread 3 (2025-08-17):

[トラブルシューティング]: test

sekigon-gonnoc, 2025-08-17:
## torabo-tsukiのトラブルシューティング

このテンプレートを使用して、キーボードの問題に関する情報を提供してください。

組み立て関連の問題をチェックしたら、対応するトラブルシュートの項目をすべてチェックしてください。
  例：ファーム書き込みの問題のいずれかにチェックを入れた -> ファームウェア書き込みのトラブルシュートの項目をすべてチェックしてください

問題の詳細やチェックした結果を、詳細説明の項目で詳しく説明してください。

フォーマットにのっとっていない場合は自動的にIssueがクローズされます。修正してReopenしてください。

最後に、BOOTHのメッセージからIssueのURLを送信してください。購入者以外のサポートはしません。

- [x] ビルドガイドの'トラブルと対策'の項目を熟読した

### 問題の分類

- キット内容の問題
  - [ ] 部品が不足している
  - [ ] 部品が破損している
  - [ ] はんだ済みの部品に問題がある
  - [ ] 組み立てに失敗したため、部品を追加購入したい
  - [ ] その他のキット内容の問題
- ファームウェア書き込みの問題
  - [x] ファームウェアが書き込めない
  - [ ] その他のファームウェア書き込みの問題
- キーボードの電源の問題
  - [ ] LEDが点灯しない
  - [ ] LEDは点灯するがペアリングしない
  - [ ] その他の電源の問題
- キー入力の問題
  - [ ] 特定のキーが反応しない
  - [ ] キーの反応が遅い
  - [ ] その他のキー入力の問題
- トラックボールの問題
  - [ ] トラックボールがまったく反応しない
  - [ ] トラックボールの動きがスムーズでない
  - [ ] カーソルの動きが不規則
  - [ ] その他のトラックボールの問題
- ペアリングの問題
  - [ ] 両手とも無線で入力できない
  - [ ] 片手（peripheral側が無線で入力できない）
  - [ ] その他のペアリングの問題
- 無線接続中の入力の問題
  - [ ] ペアリングができない
  - [ ] 接続が頻繁に切れる、接続の遅延が大きい
  - [ ] その他の無線接続中の入力の問題
- その他
  - [ ] その他

### トラブルシュート

- キット内容のトラブルシュート
  - [ ] BOOTHで連絡した <!-- ここをチェックする場合、issueは立てないでください -->
- ファームウェア書き込みのトラブルシュート
  - [x] ZMKのドキュメント、FAQを確認した
  - [x] BMPのブートローダーが起動しているかどうか、ストレージのなかのINFO_UF2.TXTを確認してからファームウェアを書き込んだ
- キーボードの電源のトラブルシュート
  - [ ] 電源ONの状態で、電池ボックスの-側とBMPの0番ピン(ランドが四角いピンの1個上)の電圧が1V以上になっている
  - [ ] 電池ボックスとスイッチのはんだ付けを再確認した <!-- 画像を添付してください -->
- キー入力のトラブルシュート
  - [ ] ZMKのドキュメント、FAQを確認した
  - [ ] central側にキーマップが設定されていることをzmk-studioで確認した
  - [ ] キースイッチの足が折れ曲がっていないか確認した
  - [ ] コンスルーの足が折れ曲がっていないか確認した
  - [ ] BMPを取り付け直した
  - [ ] BMPを左右で入れ替えて、メインの基板とBMPのどちらに問題があるか絞りこんだ
- トラックボールのトラブルシュート
  - [ ] ケーブルの接続を再確認した
  - [ ] センサーの取付位置を調整してみた
  - [ ] 組立中、ケースに取り付ける前にセンサーの動作確認を実施した
  - [ ] トラックボールモジュールの仕様(最大速度24inch/s、最大加速度10G)について理解した
- ペアリングのトラブルシュート
  - [ ] ZMKのFAQを確認し、関連するトラブルシュートを実施した(実施した内容を詳細説明に記載してください)
- 無線接続中の入力のトラブルシュート
  - [ ] ZMKのFAQを確認し、関連するトラブルシュートを実施した(実施した内容を詳細説明に記載してください)
  - [ ] ほかのデバイスに接続して動作確認した

### 問題の詳細説明

詳細説明

### トラブルシュートの詳細説明

詳細説明

### 環境情報
- ファームウェアバージョン:latest
- 接続方法（USB/Bluetooth/その他）:USB
- 接続しているデバイス（PC/Mac/その他）:PC
- OSとバージョン:win11

### 追加情報
<!-- 問題解決に役立つ可能性のあるその他の情報や画像を添付してください -->

Closed 2025-08-17.

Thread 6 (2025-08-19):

[トラブルシューティング]: Peripheralのファームウェアを書き込んだ側のキーボードのキーが全く反応しない

katsud0n-sec, 2025-08-19:
## torabo-tsukiのトラブルシューティング

このテンプレートを使用して、キーボードの問題に関する情報を提供してください。

組み立て関連の問題をチェックしたら、対応するトラブルシュートの項目をすべてチェックしてください。
  例：ファーム書き込みの問題のいずれかにチェックを入れた -> ファームウェア書き込みのトラブルシュートの項目をすべてチェックしてください

問題の詳細やチェックした結果を、詳細説明の項目で詳しく説明してください。

フォーマットにのっとっていない場合は自動的にIssueがクローズされます。修正してReopenしてください。

最後に、BOOTHのメッセージからIssueのURLを送信してください。購入者以外のサポートはしません。

- [x] ビルドガイドの'トラブルと対策'の項目を熟読した

### 問題の分類

- キット内容の問題
  - [ ] 部品が不足している
  - [ ] 部品が破損している
  - [ ] はんだ済みの部品に問題がある
  - [ ] 組み立てに失敗したため、部品を追加購入したい
  - [ ] その他のキット内容の問題
- ファームウェア書き込みの問題
  - [ ] ファームウェアが書き込めない
  - [x] その他のファームウェア書き込みの問題
- キーボードの電源の問題
  - [ ] LEDが点灯しない
  - [ ] LEDは点灯するがペアリングしない
  - [ ] その他の電源の問題
- キー入力の問題
  - [ ] 特定のキーが反応しない
  - [ ] キーの反応が遅い
  - [ ] その他のキー入力の問題
- トラックボールの問題
  - [ ] トラックボールがまったく反応しない
  - [ ] トラックボールの動きがスムーズでない
  - [ ] カーソルの動きが不規則
  - [ ] その他のトラックボールの問題
- ペアリングの問題
  - [ ] 両手とも無線で入力できない
  - [ ] 片手（peripheral側が無線で入力できない）
  - [ ] その他のペアリングの問題
- 無線接続中の入力の問題
  - [ ] ペアリングができない
  - [ ] 接続が頻繁に切れる、接続の遅延が大きい
  - [ ] その他の無線接続中の入力の問題
- その他
  - [ ] その他

### トラブルシュート

- キット内容のトラブルシュート
  - [ ] BOOTHで連絡した <!-- ここをチェックする場合、issueは立てないでください -->
- ファームウェア書き込みのトラブルシュート
  - [x] ZMKのドキュメント、FAQを確認した
  - [x] BMPのブートローダーが起動しているかどうか、ストレージのなかのINFO_UF2.TXTを確認してからファームウェアを書き込んだ
- キーボードの電源のトラブルシュート
  - [ ] 電源ONの状態で、電池ボックスの-側とBMPの0番ピン(ランドが四角いピンの1個上)の電圧が1V以上になっている
  - [ ] 電池ボックスとスイッチのはんだ付けを再確認した <!-- 画像を添付してください -->
- キー入力のトラブルシュート
  - [ ] ZMKのドキュメント、FAQを確認した
  - [ ] central側にキーマップが設定されていることをzmk-studioで確認した
  - [ ] キースイッチの足が折れ曲がっていないか確認した
  - [ ] コンスルーの足が折れ曲がっていないか確認した
  - [ ] BMPを取り付け直した
  - [ ] BMPを左右で入れ替えて、メインの基板とBMPのどちらに問題があるか絞りこんだ
- トラックボールのトラブルシュート
  - [ ] ケーブルの接続を再確認した
  - [ ] センサーの取付位置を調整してみた
  - [ ] 組立中、ケースに取り付ける前にセンサーの動作確認を実施した
  - [ ] トラックボールモジュールの仕様(最大速度24inch/s、最大加速度10G)について理解した
- ペアリングのトラブルシュート
  - [ ] ZMKのFAQを確認し、関連するトラブルシュートを実施した(実施した内容を詳細説明に記載してください)
- 無線接続中の入力のトラブルシュート
  - [ ] ZMKのFAQを確認し、関連するトラブルシュートを実施した(実施した内容を詳細説明に記載してください)
  - [ ] ほかのデバイスに接続して動作確認した

### 問題の詳細説明
Keymap editorやkeymap.keymapのソースコードを変えてファームウェアを何度かビルド・書き込みを行っていたのですが、新しいファームウェアの書き込みを行ったところ、トラックボールがついていない側のキーボードでキーが全く反応しなくなりました。(書き込んだファームウェアは[こちら](https://github.com/katsud0n-sec/zmk-keyboard-torabo-tsuki-lp/actions/runs/17038110278)になります。)原因が不明ですが、Periphieralに指定したキーボードが動いていないようです。

(補足として、書き込んだファームウェアでは、特定のレイヤーになった際にマウスカーソルを行えるようにしようとkeymap.keymapファイル・west.yamlファイルを編集してビルドしました。)

### トラブルシュートの詳細説明
- ZMKのドキュメント、FAQを確認しましたが、問題解決となる糸口は見つかりませんでした
- BMPのブートローダが起動しているかどうかを確認してからファームウェアを書き込みました　

その他に以下のことを試しており、Peripheralのファームウェアがちゃんと書き込まれていそうなのですが、うまく動いていないようです。

- Central・Peripheralを左右入れ替えてファームウェアの書き込みを行ったところ、Centralを書き込んだキーボードだけが反応する(トラックボールも正常動作)
  - 両方USBで接続、CentralをUSBで・Peripheralを無線で接続、両方無線で接続を試したが、結果は変わらない
- 左右どちらもCentralの書き込みを行ったところ、どちらもキーは反応する
  - キーボード・マイコン自体に問題はない様子
- 通常通りファームウェアを書き込み後、両方のキーボードの電源を入れると、PeripheralのキーボードのLEDでペアリング完了の点灯が必ず入る
  - Centralとの疎通はできている様子だが、Peripheralのキーボードのキーは反応しない
- Releaseの[latest](https://github.com/sekigon-gonnoc/zmk-keyboard-torabo-tsuki-lp/releases)で公開されているファームウェアをもう一度読み込んだが、結果は変わらず

### 環境情報
- ファームウェアバージョン: 自身でビルドした[ファームウェア](https://github.com/katsud0n-sec/zmk-keyboard-torabo-tsuki-lp/actions/runs/17038110278)や、Releaseの[latest](https://github.com/sekigon-gonnoc/zmk-keyboard-torabo-tsuki-lp/releases)
- 接続方法（USB/Bluetooth/その他）: USB
- 接続しているデバイス（PC/Mac/その他）: PC
- OSとバージョン: Windows 11 Pro 24H2

### 追加情報
<!-- 問題解決に役立つ可能性のあるその他の情報や画像を添付してください -->

sekigon-gonnoc, 2025-08-19:
settings_resetを書き込んでペアリングを解除してから再度ファームウェアを書き込んでみてください

sekigon-gonnoc, 2025-08-19:
peripheralだけ古いファームに戻すとどうですか？
https://github.com/sekigon-gonnoc/zmk-keyboard-torabo-tsuki-lp/actions/runs/16694490617/artifacts/3673473781

sekigon-gonnoc, 2025-08-19:
loggingを有効にしてログを確認してもらえますか？
https://zmk.dev/docs/development/usb-logging

katsud0n-sec, 2025-08-19:
すみません。マニュアルを読んでUSB loggingを有効にしたファームウェアをビルドしようとしたのですが、うまくいかないようです。どのように修正すればよいでしょうか？
- build.yamlで、snippet: studio-rpc-usb-uartをコメントアウトし、snippet: zmk-usb-loggingを追記
  - https://github.com/katsud0n-sec/zmk-keyboard-torabo-tsuki-lp/actions/runs/17070100886
- build.yamlで、複数のsnippetをリスト(snippets)として定義
  - https://github.com/katsud0n-sec/zmk-keyboard-torabo-tsuki-lp/actions/runs/17070230439

sekigon-gonnoc, 2025-08-19:
[torabo-tsuki-lp.zip](https://github.com/user-attachments/files/21856998/torabo-tsuki-lp.zip)
これを使ってください

katsud0n-sec, 2025-08-19:
CentralとPeripheralで以下のようなログが出ました。
[central.log](https://github.com/user-attachments/files/21858376/central.log)
[peripheral.log](https://github.com/user-attachments/files/21858377/peripheral.log)

Peripheralのログを見ると、`zmk: Failed to start advertising (-22)`となっており、Central側のキーボードに知らせるためのadvertisingが開始できなかったようです。

sekigon-gonnoc, 2025-08-20:
その前に`[00:00:06.952,880] <wrn> bt_conn: Found valid connection (0x200039b8) with address 00:1A:7D:DA:71:15 (public) in disconnected state`と出ているので、settings_resetがうまくできてない気がします。

settings_resetはuf2を書き込むだけでなく、一度再起動が必要です
書き込み→USB外す→スイッチON→USB再接続

katsud0n-sec, 2025-08-20:
```
settings_resetはuf2を書き込むだけでなく、一度再起動が必要です
書き込み→USB外す→スイッチON→USB再接続
```

試してみたところ、Peripheralのキーが反応するようになりました！ありがとうございます。
リセットのやり方が間違っていたんですね。書き込みだけやっていました...。

Closed 2025-08-20.

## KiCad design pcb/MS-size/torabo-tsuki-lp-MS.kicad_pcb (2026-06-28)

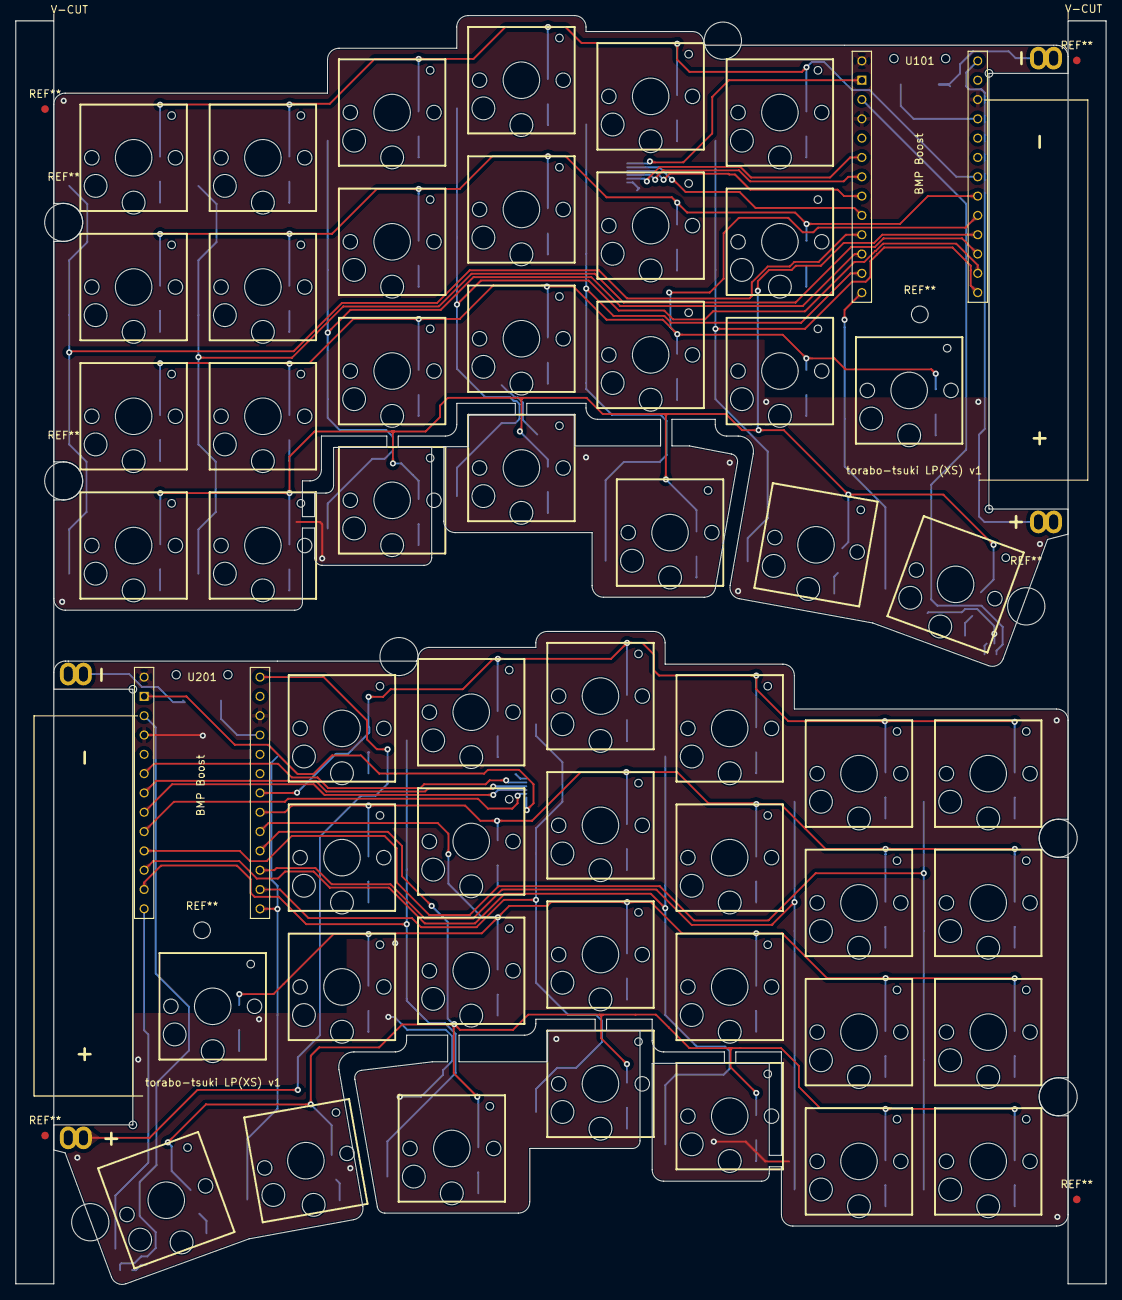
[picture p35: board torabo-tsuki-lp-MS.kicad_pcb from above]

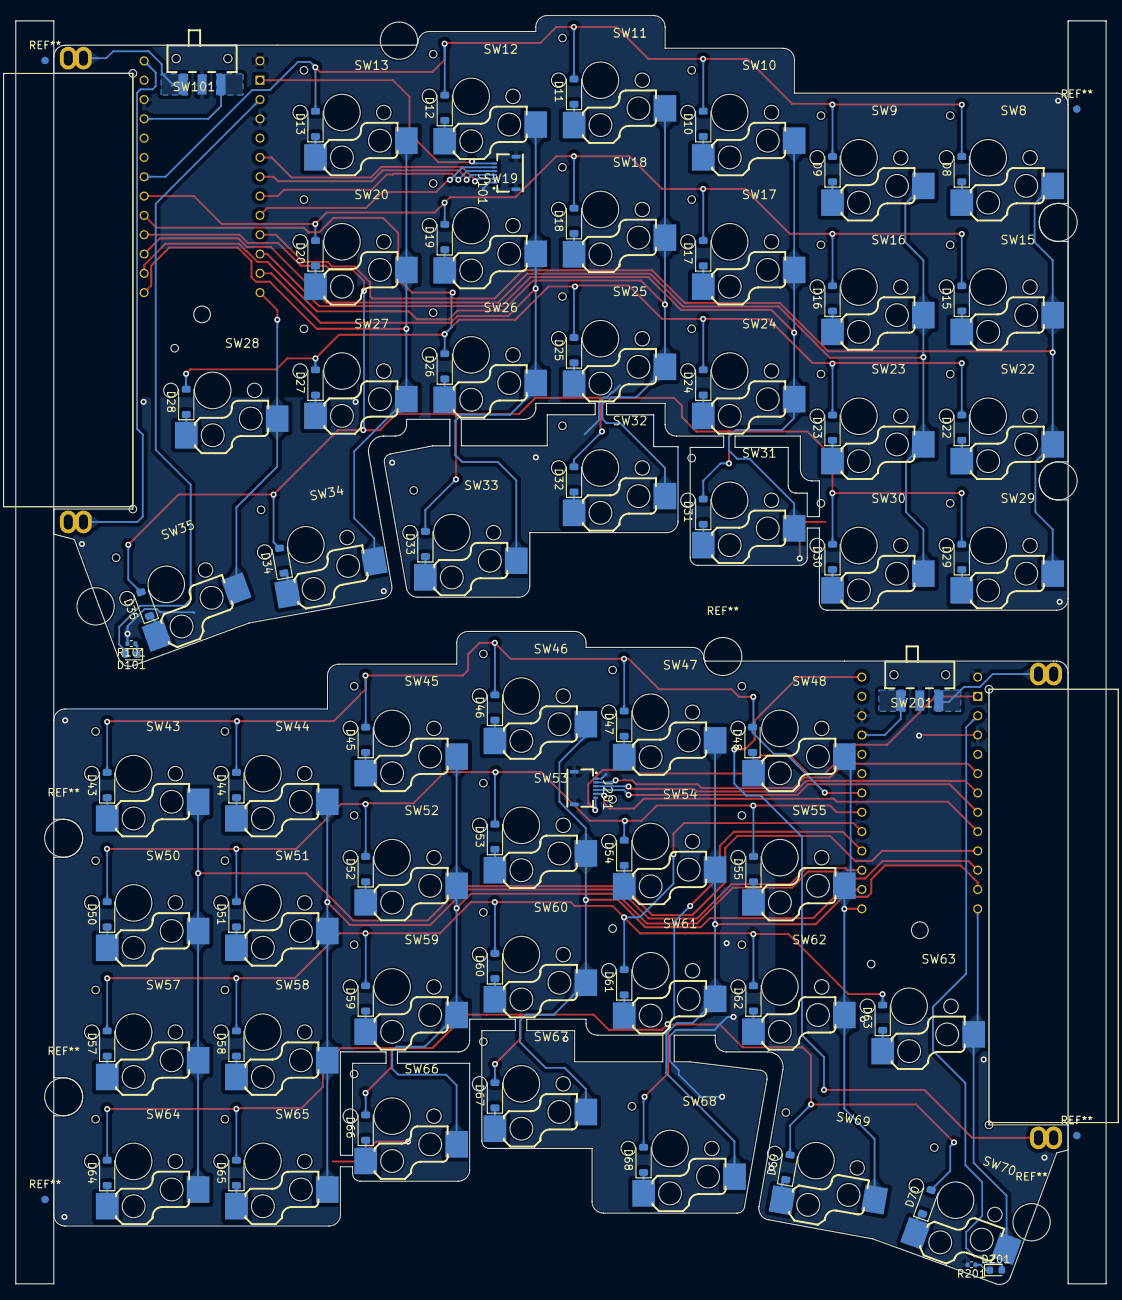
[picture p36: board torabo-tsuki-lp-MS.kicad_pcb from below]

Board: 2 copper layers, 143.4 x 166.9 mm, 118 parts (114 on the bottom side), 93 nets.

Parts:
BT101, BT201: Battery_Cell; battery_holder
BT102, BT202: Battery_Cell; AAA_Battery_DIP
D8, D9, D10, D11, D12, D13, D15, D16, D17, D18, D19, D20, D22, D23, D24, D25, D26, D27, D28, D29, D30, D31, D32, D33, D34, D35, D43, D44, D45, D46, D47, D48, D50, D51, D52, D53, D54, D55, D57, D58, D59, D60, D61, D62, D63, D64, D65, D66, D67, D68, D69, D70: D_Small; D_SOD-123
D101, D201: LED_Small; LED_0603_1608Metric
J101, J201: Conn_01x06_MountingPin; GT-F0501SR10-06S1101
R101, R201: 330; R_0402_1005Metric
SW8, SW9, SW10, SW11, SW12, SW13, SW15, SW16, SW17, SW18, SW19, SW20, SW22, SW23, SW24, SW25, SW26, SW27, SW28, SW29, SW30, SW31, SW32, SW33, SW34, SW35, SW43, SW44, SW45, SW46, SW47, SW48, SW50, SW51, SW52, SW53, SW54, SW55, SW57, SW58, SW59, SW60, SW61, SW62, SW63, SW64, SW65, SW66, SW67, SW68, SW69, SW70: SW_Push; CHOC_V2_SOCKET_HANDSOLDERING
SW101, SW201: SW_SPDT; SW-SMD_K3-1280S-F1
U101, U201: BLEMicroPro

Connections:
+BATT: BT101.1 (+), BT102.1 (+), BT201.1 (+), BT202.1 (+), U101.26 (BAT), U201.26 (BAT)
/left/BOOT: SW101.3 (C), U101.23 (BOOT)
/left/COL0: SW8.1, SW15.1, SW22.1, SW29.1, U101.10 (22)
/left/COL1: SW9.1, SW16.1, SW23.1, SW30.1, U101.16 (47)
/left/COL2: SW10.1, SW17.1, SW24.1, SW31.1, U101.11 (23)
/left/COL3: SW11.1, SW18.1, SW25.1, SW32.1, U101.15 (10)
/left/COL4: SW12.1, SW19.1, SW26.1, SW33.1, U101.12 (32)
/left/COL5: SW13.1, SW20.1, SW27.1, SW34.1, U101.14 (9)
/left/COL6: SW28.1, SW35.1, U101.13 (35)
/left/CS: J101.5, U101.9 (20)
/left/LED: D101.2 (A), U101.3 (11)
/left/MOTION: J101.4, U101.8 (19)
/left/ROW1: D8.2 (A), D9.2 (A), D10.2 (A), D11.2 (A), D12.2 (A), D13.2 (A), U101.20 (0)
/left/ROW2: D15.2 (A), D16.2 (A), D17.2 (A), D18.2 (A), D19.2 (A), D20.2 (A), U101.19 (30)
/left/ROW3: D22.2 (A), D23.2 (A), D24.2 (A), D25.2 (A), D26.2 (A), D27.2 (A), D28.2 (A), U101.18 (3)
/left/ROW4: D29.2 (A), D30.2 (A), D31.2 (A), D32.2 (A), D33.2 (A), D34.2 (A), D35.2 (A), U101.17 (46)
/left/SCLK: J101.2, U101.6 (18)
/left/SDIO: J101.3, U101.7 (16)
/right/BOOT: SW201.1 (A), U201.23 (BOOT)
/right/COL0: SW43.1, SW50.1, SW57.1, SW64.1, U201.10 (22)
/right/COL1: SW44.1, SW51.1, SW58.1, SW65.1, U201.16 (47)
/right/COL2: SW45.1, SW52.1, SW59.1, SW66.1, U201.11 (23)
/right/COL3: SW46.1, SW53.1, SW60.1, SW67.1, U201.15 (10)
/right/COL4: SW47.1, SW54.1, SW61.1, SW68.1, U201.12 (32)
/right/COL5: SW48.1, SW55.1, SW62.1, SW69.1, U201.14 (9)
/right/COL6: SW63.1, SW70.1, U201.13 (35)
/right/CS: J201.5, U201.9 (20)
/right/LED: D201.2 (A), U201.3 (11)
/right/MOTION: J201.4, U201.8 (19)
/right/ROW1: D43.2 (A), D44.2 (A), D45.2 (A), D46.2 (A), D47.2 (A), D48.2 (A), U201.20 (0)
/right/ROW2: D50.2 (A), D51.2 (A), D52.2 (A), D53.2 (A), D54.2 (A), D55.2 (A), U201.19 (30)
/right/ROW3: D57.2 (A), D58.2 (A), D59.2 (A), D60.2 (A), D61.2 (A), D62.2 (A), D63.2 (A), U201.18 (3)
/right/ROW4: D64.2 (A), D65.2 (A), D66.2 (A), D67.2 (A), D68.2 (A), D69.2 (A), D70.2 (A), U201.17 (46)
/right/SCLK: J201.2, U201.6 (18)
/right/SDIO: J201.3, U201.7 (16)
GND: J101.1, J101.MP (MountPin), J201.1, J201.MP (MountPin), R101.2, R201.2, SW101.2 (B), SW201.2 (B), U101.1 (GND), U101.4 (GND), U101.24 (GND), U201.1 (GND), U201.4 (GND), U201.24 (GND)
unnamed: BT101.2 (-), BT102.2 (-), SW101.1 (A)
unnamed: BT201.2 (-), BT202.2 (-), SW201.3 (C)
unnamed: D8.1 (K), SW8.2
unnamed: D9.1 (K), SW9.2
unnamed: D10.1 (K), SW10.2
unnamed: D11.1 (K), SW11.2
unnamed: D12.1 (K), SW12.2
unnamed: D13.1 (K), SW13.2
unnamed: D15.1 (K), SW15.2
unnamed: D16.1 (K), SW16.2
unnamed: D17.1 (K), SW17.2
unnamed: D18.1 (K), SW18.2
unnamed: D19.1 (K), SW19.2
unnamed: D20.1 (K), SW20.2
unnamed: D22.1 (K), SW22.2
unnamed: D23.1 (K), SW23.2
unnamed: D24.1 (K), SW24.2
unnamed: D25.1 (K), SW25.2
unnamed: D26.1 (K), SW26.2
unnamed: D27.1 (K), SW27.2
unnamed: D28.1 (K), SW28.2
unnamed: D29.1 (K), SW29.2
unnamed: D30.1 (K), SW30.2
unnamed: D31.1 (K), SW31.2
unnamed: D32.1 (K), SW32.2
unnamed: D33.1 (K), SW33.2
unnamed: D34.1 (K), SW34.2
unnamed: D35.1 (K), SW35.2
unnamed: D43.1 (K), SW43.2
unnamed: D44.1 (K), SW44.2
unnamed: D45.1 (K), SW45.2
unnamed: D46.1 (K), SW46.2
unnamed: D47.1 (K), SW47.2
unnamed: D48.1 (K), SW48.2
unnamed: D50.1 (K), SW50.2
unnamed: D51.1 (K), SW51.2
unnamed: D52.1 (K), SW52.2
unnamed: D53.1 (K), SW53.2
unnamed: D54.1 (K), SW54.2
unnamed: D55.1 (K), SW55.2
unnamed: D57.1 (K), SW57.2
unnamed: D58.1 (K), SW58.2
unnamed: D59.1 (K), SW59.2
unnamed: D60.1 (K), SW60.2
unnamed: D61.1 (K), SW61.2
unnamed: D62.1 (K), SW62.2
unnamed: D63.1 (K), SW63.2
unnamed: D64.1 (K), SW64.2
unnamed: D65.1 (K), SW65.2
unnamed: D66.1 (K), SW66.2
unnamed: D67.1 (K), SW67.2
unnamed: D68.1 (K), SW68.2
unnamed: D69.1 (K), SW69.2
unnamed: D70.1 (K), SW70.2
unnamed: D101.1 (K), R101.1
unnamed: D201.1 (K), R201.1
VCC: J101.6, J201.6, U101.2 (8), U201.2 (8)

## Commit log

2026-06-17 Add XS(v1) plate date
    [torabo-tsuki-lp-XS-bottom.kicad_pcb, torabo-tsuki-lp-XS-top-key.kicad_pcb, torabo-tsuki-lp-XS-top.kicad_pcb]
2026-06-22 Add XS, L size pcb data
    [left.kicad_sch, right.kicad_sch, torabo-tsuki-lp-L-bottom.kicad_pcb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]
2026-06-28 Add MS-size
    [left.kicad_sch, right.kicad_sch, torabo-tsuki-lp-MS-bottom.kicad_pcb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]
2026-08-02 fix typo
    [torabo-tsuki-lp-ms-simple-case.FCStd]
2026-08-19 トラブルシュート項目を追加
